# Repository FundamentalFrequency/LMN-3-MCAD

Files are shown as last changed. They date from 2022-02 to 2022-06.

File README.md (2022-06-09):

# LMN-3-MCAD

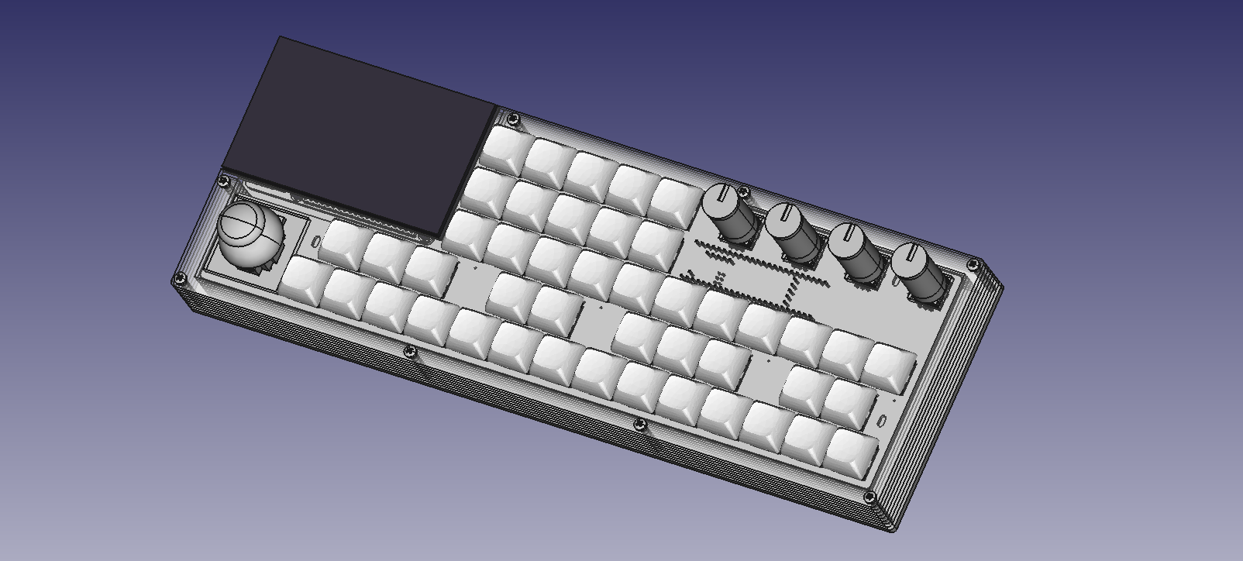
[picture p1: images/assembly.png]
screenshot of Assembly


This repository contains the [FreeCAD](https://www.freecadweb.org/) project files for the LMN-3 Enclosure.

If you would like to support the project, please consider becoming a [sponsor](https://github.com/sponsors/stonepreston).

## Releases
Releases containing DXF and STL files are available [here](https://github.com/FundamentalFrequency/LMN-3-MCAD/releases). 

## Manufacturing

### Layers
The enclosure is designed to be assembled from multiple laser-cut acrylic or wood layers. DXF files are available in the releases [here](https://github.com/FundamentalFrequency/LMN-3-MCAD/releases). 3-D printing these layers is also possible. 

| Layer Name | Layer Thickness (mm) | Quantity |
|---|---|---|
| Bottom Layer | 3 | 1 |
| Lower Layer  | 3 | 6 |
| Top Layer | 3 | 2 |
| Switch Layer | 3 | 1 |

Note that although 6 lower layers are recommended, you may end up only needing 5. Manufacturing an extra lower layer is helpful in case the thickness of your acrylic is a bit less than 3 mm. With so many layers, the difference adds up, and your enclosure can end up being a bit thinner than intended. Having an extra lower layer to throw in can help with that issue. 

Because the upper and lower layers are not fully enclosed, you can save material by placing one layer inside the other when laying out your cutting path:

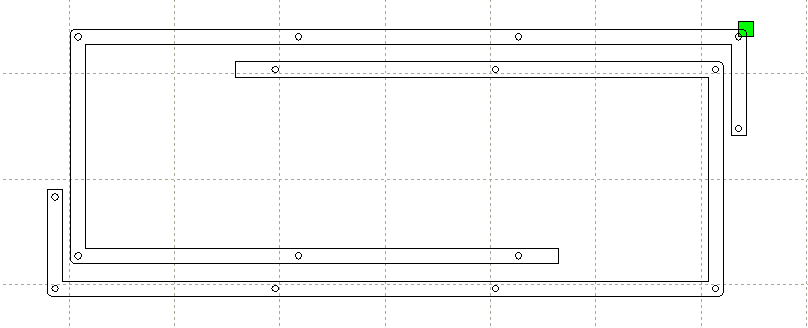
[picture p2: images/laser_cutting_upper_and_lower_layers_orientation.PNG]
Cutting path


#### Laser Cutting Services
If you are unable to laser cut the parts yourself, there are plenty of online shops available that you can use. These shops allow you to submit DXF files and specify a material, and they will cut the parts and ship them to you. If you would like to save a bit of money, you can see if a makerspace is available in your area (this is what I ended up doing). It can be a fun way to learn something new

### Fasteners

| Fastener | Quantity |
|---|---|
| M2.5x30 Bolt | 8 |
| M2.5x12 Bolt | 4 |
| M2.5 Nut | 8 |

The M2.5x30 bolts are for fastening the layers together. The M2.5x12 bolts are for fastening the Raspberry Pi to the bottom of the case (they screw into the standoffs that come with the screen.)

It is also advisable to purchase some adhesive rubber feet for the bottom of the enclosure. 

### 3-D Printing
You can also 3-D print all the layers using the STL files provided in the [releases](https://github.com/FundamentalFrequency/LMN-3-MCAD/releases). However, depending on the size of your print bed you may need to post-process the files a bit in order to fit them on your printer bed. You can cut them in half (maybe use a stair-step-shaped cut to provide some surface area for gluing) and then print parts in 2 pieces. Post-processed STL files are not provided, as everyone's printer is different, and it would be too much work to provide enough sizes to keep everyone happy. Feel free to modify the FreeCAD part files yourself and re-export modified STLs, or manipulate the released STL meshes. 

If you would like to process the parts using FreeCAD, you may find [this video](https://www.youtube.com/watch?v=tzHkQaHgrfQ) helpful. 

## Contributing
### FreeCAD
The files in this repository compose a [FreeCAD](https://www.freecadweb.org/) project. It is recommended you use FreeCAD 20. You will need to install two addons, Assembly4 and Fasteners. A full assembly is provided in `assemblies/` and individual part files can be found in their respective folders. Additional STEP files are also included for the PCB and other objects. 

#### Some Design Rules
##### The Topological Naming Problem
FreeCAD suffers from something known as the topological naming problem. What that is is outside the scope of this document, but remember this: DO NOT SKETCH DIRECTLY ON PART FACES. If you draw directly on part faces, you will face this problem at some point. It is therefore best to not sketch on faces ever. Sketch on translated datum planes or origin planes, but never a face of a part. 

##### The Master Spreadsheet
FreeCAD includes a spreadsheet concept. Part parameters are all enumerated in the master spreadsheet, located within the `master.FCStd` file. All parts should use the values provided in this spreadsheet when dimensioning, in order to keep the design as parametric as possible. 

## Thanks
This project would not be possible without the following free and open source projects:
- [FreeCAD](https://www.freecadweb.org/)

### Sources for 3-D Models
#### Raspberry Pi 4
- [3-D Model](https://grabcad.com/library/raspberry-pi-4-model-b-1)

#### Encoders (Alps EC11E09244AQ)
- [3-D Model](https://www.snapeda.com/parts/EC11E09244AQ/ALPS/view-part/?welcome=home&t=EC11E)

#### Teensy 4.1
- [3-D Model](https://www.snapeda.com/parts/DEV-16771/SparkFun%20Electronics/view-part/?t=teensy)

#### Thumbstick (SparkFun COM-09032)
- [3-D Model](https://www.snapeda.com/parts/COM-09032/SparkFun%20Electronics/view-part/?t=joystick)

#### Keyboard Switches (Keyswitch Kicad Library)
- [3-D Models](https://github.com/perigoso/keyswitch-kicad-library)

## License
Licensed under the [CC-by-SA 4.0](https://creativecommons.org/licenses/by-sa/4.0/) license.

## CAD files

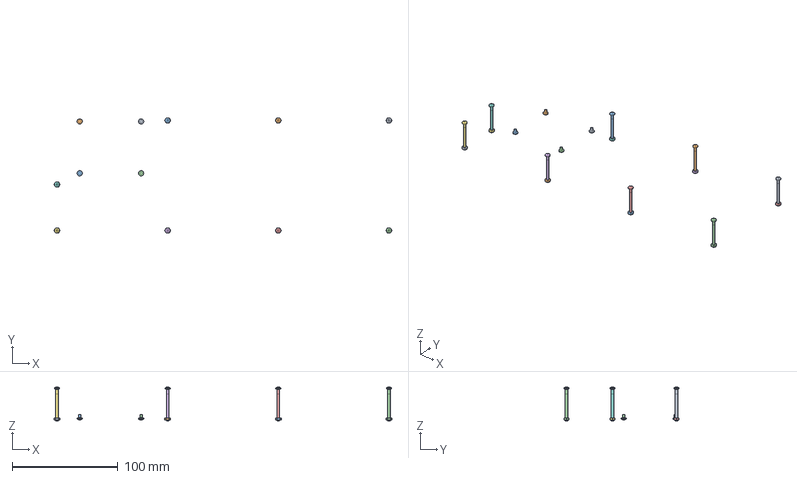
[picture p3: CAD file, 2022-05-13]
assemblies/assembly.FCStd
319.3 x 109.0 x 32.0 mm
M2.5x30-Screw
M2.5x30-Screw035
M2.5x30-Screw036
M2.5x30-Screw037
M2.5x30-Screw038
M2.5x30-Screw039
M2.5x30-Screw040
M2.5x30-Screw041
M2.5-Nut
M2.5-Nut092
M2.5-Nut093
M2.5-Nut094
M2.5-Nut095
M2.5-Nut096
M2.5-Nut097
M2.5-Nut098
M2.5x3-Screw
M2.5x3-Screw057
M2.5x3-Screw058
M2.5x3-Screw059

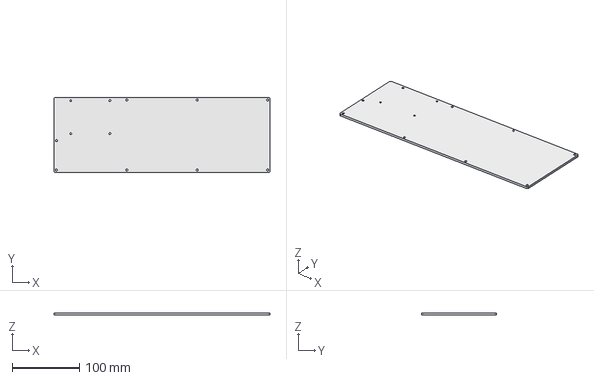
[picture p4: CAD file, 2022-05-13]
bottom_layer/bottom_layer.FCStd
320.7 x 111.2 x 3.00 mm

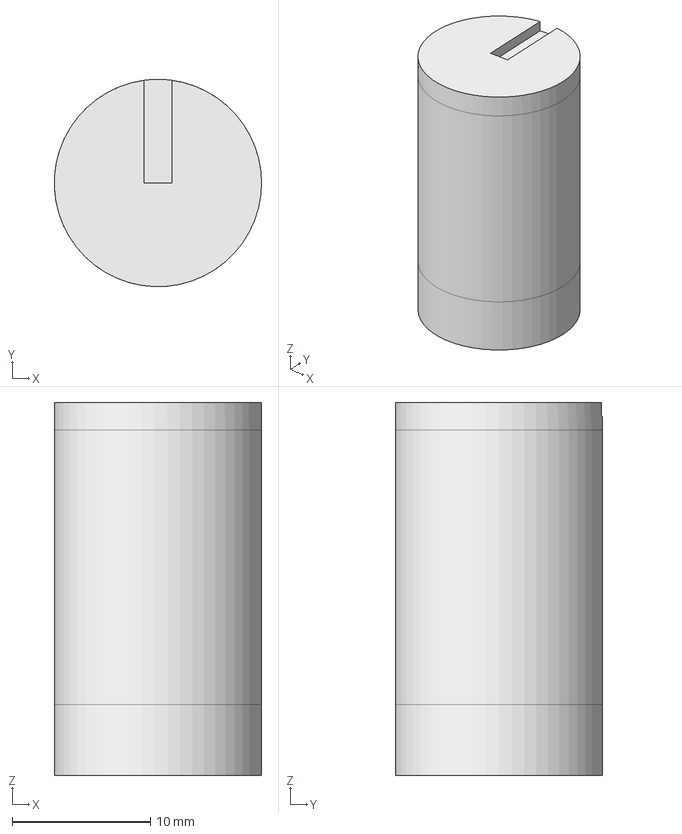
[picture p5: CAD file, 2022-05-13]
encoder_knob/encoder_knob.FCStd
15.0 x 15.0 x 27.0 mm

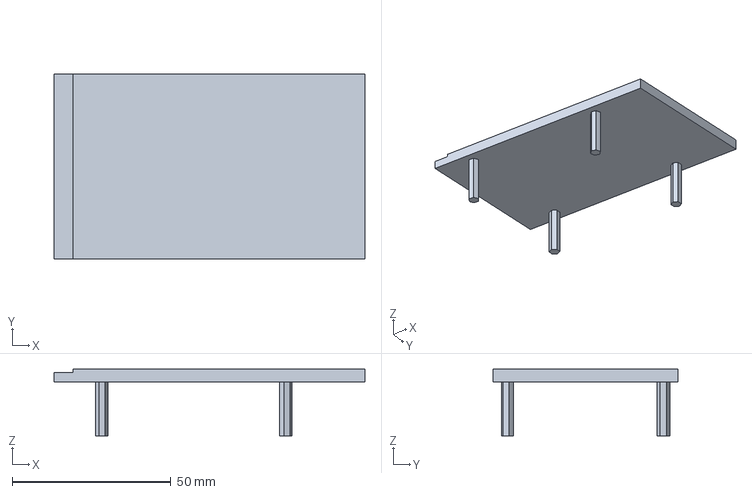
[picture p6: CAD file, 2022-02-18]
hyperpixel/hyperpixel.step
98.0 x 58.2 x 21.0 mm

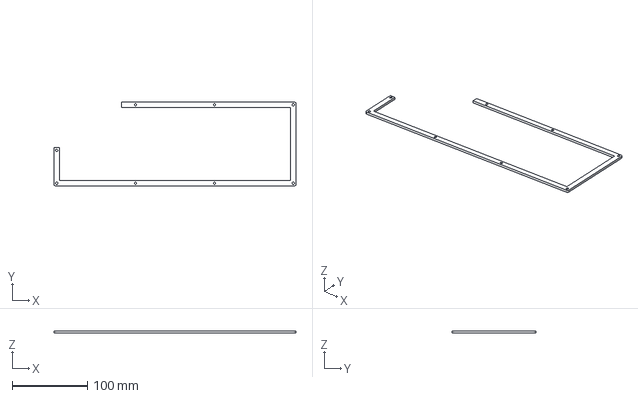
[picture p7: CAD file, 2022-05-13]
lower_layer/lower_layer.FCStd
320.7 x 111.2 x 3.00 mm

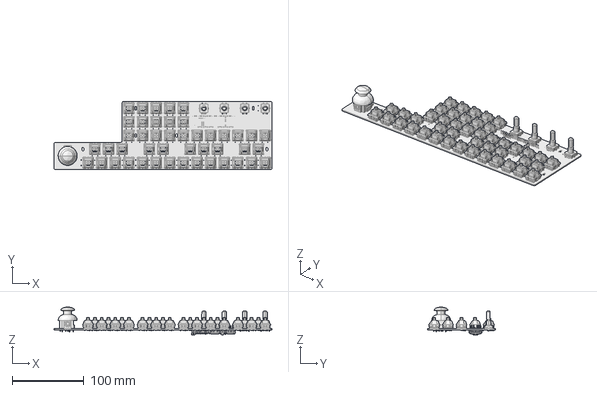
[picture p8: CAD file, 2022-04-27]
pcb/pcb.FCStd
304.8 x 95.2 x 39.1 mm

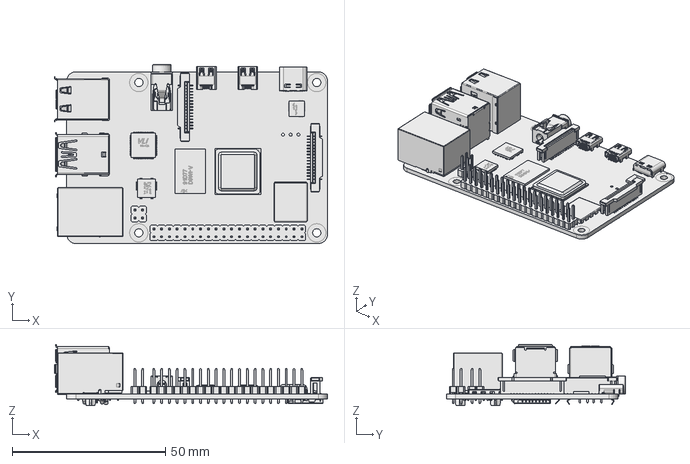
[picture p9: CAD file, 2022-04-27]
raspberry_pi/raspberry_pi_4.FCStd
89.0 x 58.4 x 19.9 mm

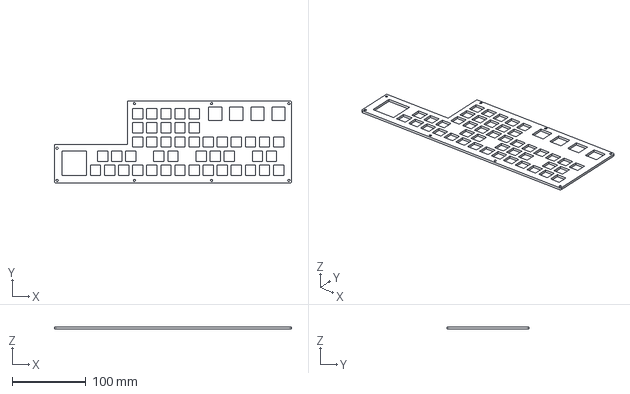
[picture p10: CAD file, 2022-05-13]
switch_layer/switch_layer.FCStd
320.7 x 111.2 x 3.00 mm

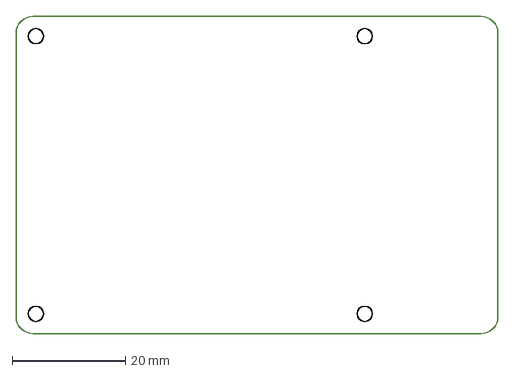
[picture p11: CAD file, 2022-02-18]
raspberry_pi/mechanical_drawing.dxf
85.0 x 56.0 mm

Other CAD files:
master.FCStd
top_layer/top_layer.FCStd
hyperpixel/hyperpixel.FCStd

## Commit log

2022-02-18 Add screws for pi to assembly, remove unnecessary files
    [assembly.FCStd, assembly2.FCStd, bottom_layer.FCStd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]
2022-02-22 Update 3-D printed switch layer
    [master.FCStd, sides_assembly.FCStd, switch_layer_A.stl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]
2022-02-24 Update PCB and assembly
    [assembly.FCStd, bottom_layer.FCStd, hyperpixel.FCStd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]
2022-02-28 Update hyperpixel to use master spreadsheet
    [hyperpixel.FCStd]
2022-03-21 Add keycaps, encoder knobs
    [assembly.FCStd, bottom_layer.FCStd, encoder_knob.FCStd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]
2022-04-14 Change hyperpixel to be touch screen model, remove thin top layer, adjust screw offsets
    [assembly.FCStd, bottom_layer.FCStd, encoder_knob.FCStd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]
2022-04-27 Remove keycaps code
    [keycaps.scad]
2022-05-13 Clean up files a bit
    [1_25_key.scad, assembly.FCStd, bottom_A.stl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]
2022-05-19 Clean up files
    [pcb.dxf, switch_layer-Sketch008.dxf]
